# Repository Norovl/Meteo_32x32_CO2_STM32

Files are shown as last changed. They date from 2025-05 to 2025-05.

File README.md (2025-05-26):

Данный проект представляет собой метеостанцию с дополнительными возможностями, собранную на основе STM32F103C8T6.

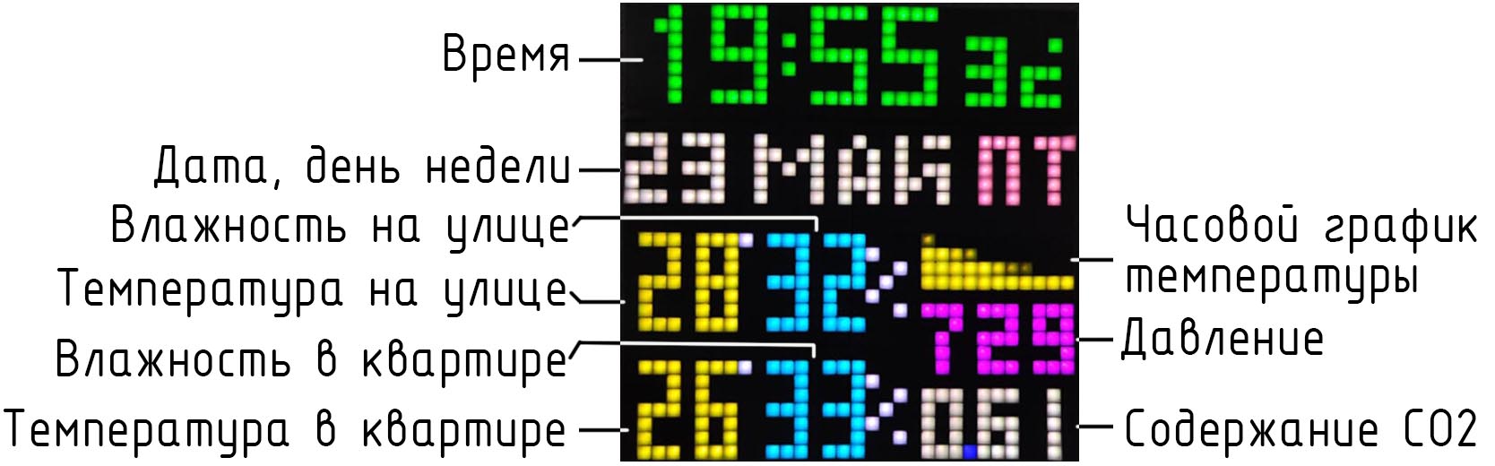
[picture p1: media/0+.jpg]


Станция может показывать:

**На главном экране:**

*   Время (часы);
*   Дату (число, месяц, день недели);
*   Температуру (ͦС) и влажность (%) на улице;
*   Температуру (ͦС) и влажность (%) в квартире;
*   Атмосферное давление воздуха (мм.рт.ст.)
*   Содержание СО2 в квартире (тыс.ppm);
*   Часовой график температуры (влажности, давления) на улице и/или температуру (влажность, СО2) в квартире.

**На дополнительных экранах:**

*   Текущую температуру (ͦС), влажность (относительную (%) и абсолютную (г/м3)), точку росы в квартире и на улице, давление, СО2 (ppm) с текущим минутным графиком по каждому из показателей;
*   Значение час назад и текущее значение температуры, влажности (относительной (%) и абсолютной (г/м3)), точки росы (ͦС) в квартире и на улице, давления, СО2 (ppm) с часовым графиком по каждому из показателей;
*   Суточный график с последовательным выводом значения за каждый час суток по следующим показателям: температура, влажность (относительная и абсолютная), точка росы в квартире и на улице, давление, СО2.

**Аппаратный состав проекта:**

([https://aliexpress.ru/item/1005003541972572.html?spm=a2g2w.orderdetail.0.0.49934aa6X7jbTa&sku\_id=12000026227682554&\_ga=2.192225709.602763749.1748060249-1858461858.1585985510](https://aliexpress.ru/item/1005003541972572.html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))

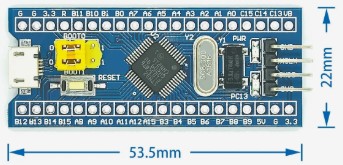
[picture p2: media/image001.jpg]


Состав датчиков:

1.  Два датчика BME280 (температура, влажность, давление). У одного из них нужно перепаять дорожку для изменения адреса подключения;

([https://aliexpress.ru/item/32862445164.html?spm=a2g2w.orderdetail.0.0.24634aa6IzSH7J&sku\_id=10000000058075622&\_ga=2.255525007.602763749.1748060249-1858461858.1585985510](https://aliexpress.ru/item/32862445164.html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))  
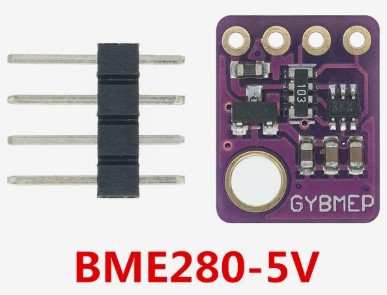
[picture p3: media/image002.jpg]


2.  Датчик MH-Z19B (СО2);

([https://aliexpress.ru/item/32371956420.html?sku\_id=12000035236616579&spm=a2g2w.productlist.search\_results.0.7c71c19cK1bYaC](https://aliexpress.ru/item/32371956420.html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))  
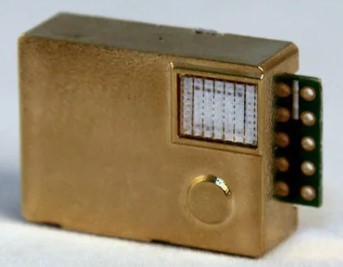
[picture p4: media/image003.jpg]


3.  Фоторезистор (необязателен) – нужен для автоматической регулировки яркости при изменении внешнего освещения).

([https://aliexpress.ru/item/1005007944797703.html?sku\_id=12000042961408154&spm=a2g2w.productlist.search\_results.1.56b92e913V1ALD](https://aliexpress.ru/item/1005007944797703.html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))

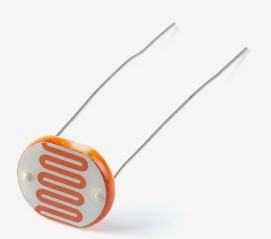
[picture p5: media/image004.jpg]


4.  В качестве панели отображения используются четыре WS2812B PIXELS PANEL размером 8 х 32 пикселей, соединенные сверху вниз, подключенные к контроллеру в нижнем углу (подключение и расположение панелей можно менять в настройках проекта).

([https://aliexpress.ru/item/4000544584524.html?spm=a2g2w.orderdetail.0.0.23ba4aa6R5I62Q&sku\_id=12000032067904150&\_ga=2.163242171.602763749.1748060249-1858461858.1585985510](https://aliexpress.ru/item/4000544584524.html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))

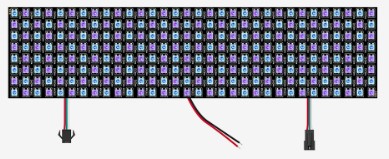
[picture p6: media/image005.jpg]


В качестве рассеивателя используется распечатанная на 3D принтере белая пластина в 2-3 слоя, наклеенная на черную распечатанную сетку.
В проекте приложены модели сетки и пластины размерами 8х8 и 16х8 пикселей. Для размера 32х32 нужно распечатать несколько сеток и пластин и склеить между собой. 
Обратите внимание - у сетки есть верх и низ. Сторона для наклеивания пластины плоская, на другой стороне часть сетки приподнято для сохранения места под резисторы обвязки панели.

Сетка:

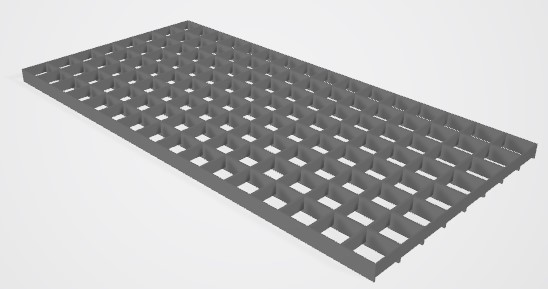
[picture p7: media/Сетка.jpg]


**Схема подключения:**

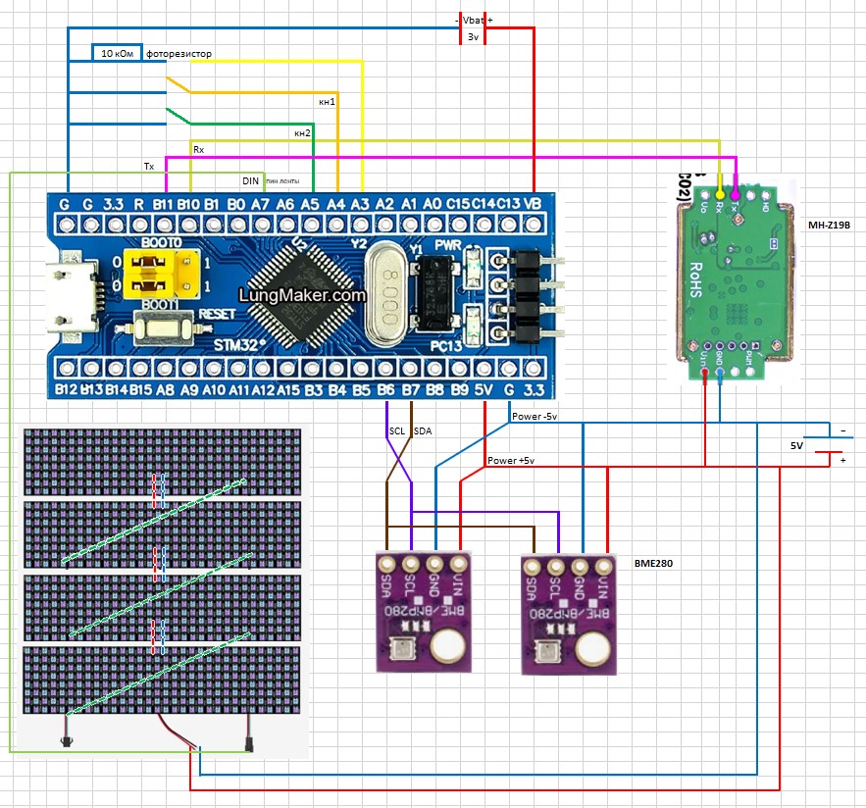
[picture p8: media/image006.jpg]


**Управление и настройка метеостанции:**

**Двойное нажатие** \[кн.1\] – в режим установки даты и времени. 
Дальнейшие нажатия \[кн.1\] - последовательное переключение настройки Год – Месяц – Число – Часы – Минуты – Секунды – Корректировка скорости хода часов\*.

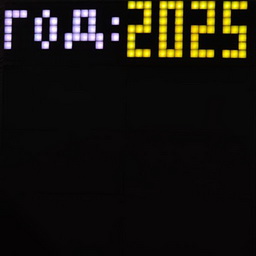
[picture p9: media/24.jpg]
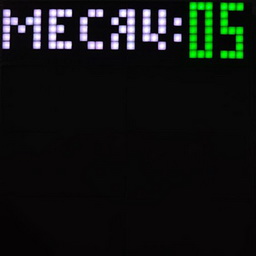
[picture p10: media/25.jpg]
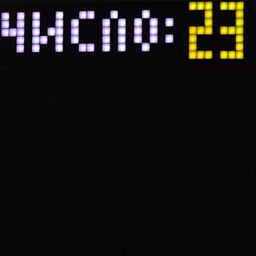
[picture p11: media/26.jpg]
  

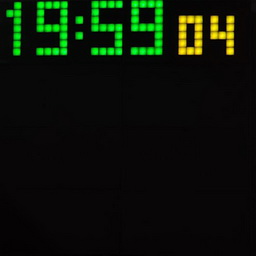
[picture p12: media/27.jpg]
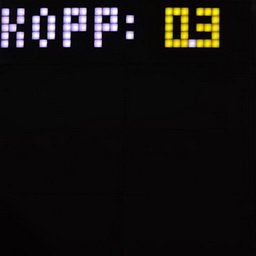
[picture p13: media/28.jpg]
 

Выйти из режима настройки - удержание \[кн.1\] или переключение последовательно всех настраиваемых элементов

Установка даты/времени производится путем:

**одинарного нажатия** \[кн.2\] - увеличение на единицу настраиваемое значение;

**удержания** \[кн.2\] - постоянное увеличение настраиваемого значения пока нажата кнопка;

**Двойного нажатия** \[кн.2\] – уменьшение на единицу настраиваемого значения;

**Двойного нажатия и удержания на втором нажатии \[кн.2\]** – постоянное уменьшение настраиваемого значения пока нажата кнопка

\*настройка скорости хода часов (сек/сут) (фактическая корректировка производится на целые секунды, т.е. если корректировка установлена как 0,2, то 1 раз в 5 суток добавляется 1 секунда);

**Пятикратное нажатие** \[кн.2\] – сохраняются настройки вида отображения показаний датчиков и часовых графиков.

**Одинарное нажатие** \[кн.2\] – последовательное переключение показаний в нижней части табло \[currentMode\]:

1.  (показания на улице (Out)) Температура + Влажность + График(и)/давление, (показания в квартире (In)) Температура + Влажность + График(и)/СО2. (отрицательные значения температуры отображаются синим цветом); \[0\]

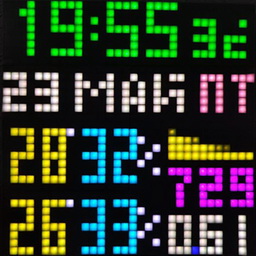
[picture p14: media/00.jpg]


2.  Температура на улице и в квартире до тысячных долей + часовой график; \[1\]

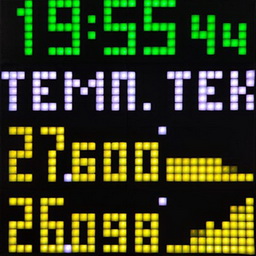
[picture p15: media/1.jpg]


3.  Относительная влажность (%) на улице и в квартире + часовой график; \[2\]

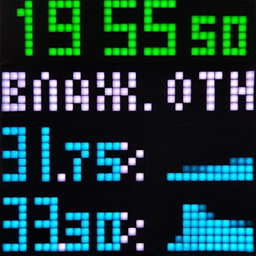
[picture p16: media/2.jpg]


4.  Абсолютная влажность (г/м3) на улице и в квартире + часовой график; \[3\]

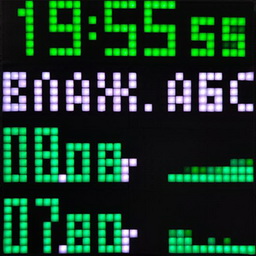
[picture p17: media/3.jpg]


5.  Давление до тысячных долей и содержание СО2 в квартире PPM; \[4\]  
    
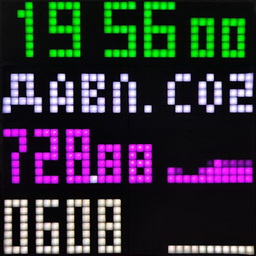
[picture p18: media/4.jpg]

	
6.  Точка росы на улице и в квартире + часовой график; \[5\]  
    
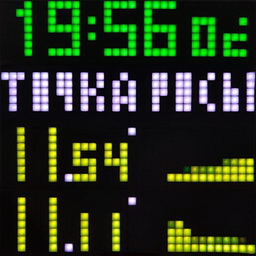
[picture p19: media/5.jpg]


7.  Температура за час (на начало и конец часа) на улице и в квартире; \[10\]  
	
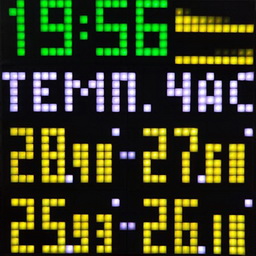
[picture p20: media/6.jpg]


8.  Относительная влажность (%) за час (на начало и конец часа) на улице и в квартире; \[11\]  
    
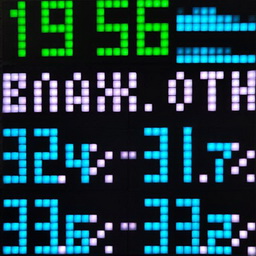
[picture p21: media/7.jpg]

	
9.  Абсолютная влажность (г/м3) за час (на начало и конец часа) на улице и в квартире; \[12\]
	
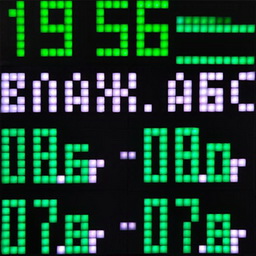
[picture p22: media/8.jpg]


10.  Давление и содержание СО2 за час (на начало и конец часа); \[13\]

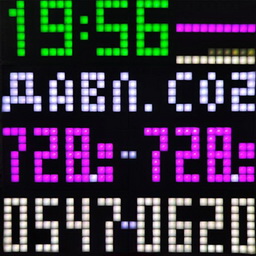
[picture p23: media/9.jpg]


11.  Точка росы за час (на начало и конец часа) на улице и в квартире; \[14\]

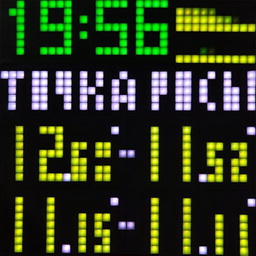
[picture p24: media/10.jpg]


12.  Суточный график температуры на улице и в квартире с последовательным отображением показаний за каждый час суток\*; \[20\]

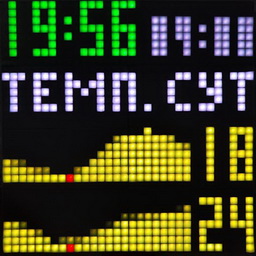
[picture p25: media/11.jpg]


13.  Суточный график относительной влажности (%) на улице и в квартире с последовательным отображением показаний за каждый час суток; \[21\]

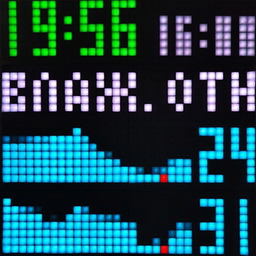
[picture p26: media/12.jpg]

	
14.  Суточный график абсолютной влажности (г/м3) на улице и в квартире с последовательным отображением показаний за каждый час суток; \[22\]

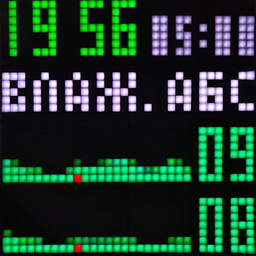
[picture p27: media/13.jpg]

	
15.  Суточный график давления и содержания СО2 с последовательным отображением показаний за каждый час суток; \[23\]

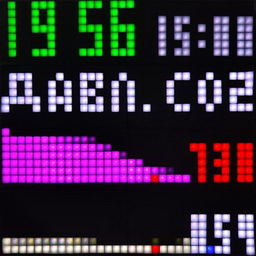
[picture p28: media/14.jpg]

	
16.  Суточный график точки росы на улице и в квартире с последовательным отображением показаний за каждый час суток; \[24\]

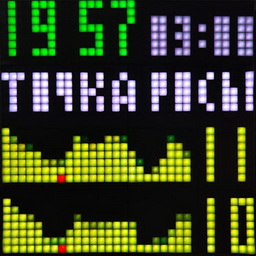
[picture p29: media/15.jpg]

	
\*в суточных графиках добавляется красная метка в нижней части, справа от графика отображается значение показателя (температура In, Out, влажность In, Out, давление, СО2, точка росы In, Out).

**Удержание** \[кн.1\] – автоматическое последовательное переключение показаний в нижней части табло как при одинарном нажатии.

**Одинарное нажатие** \[кн.1\] – переключение показаний в правой части 3 и 4 секции из 4-х:

1.  Часовой график температуры (влажности, давления)\* Out, давление, СО2


	
2.  Крупно давление, СО2

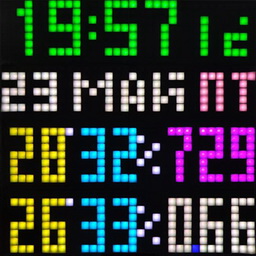
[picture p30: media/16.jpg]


3.  Часовой график температуры (влажности, давления) Out, давление, часовой график СО2 (температуры, влажности) In

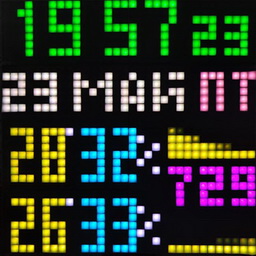
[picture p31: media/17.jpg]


4.  Крупно часовой график температуры (влажности, давления) Out, СО2

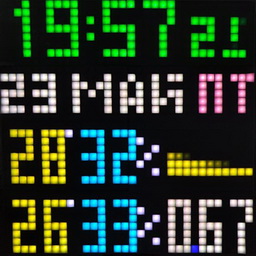
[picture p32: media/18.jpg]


5.  Часовой график температуры (влажности, давления) и влажности (давления, температуры) Out, СО2

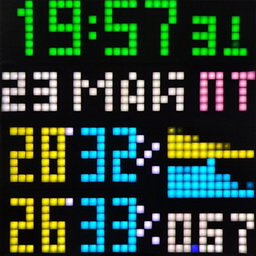
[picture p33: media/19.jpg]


6.  Крупно давление, часовой график СО2 (температуры, влажности) In

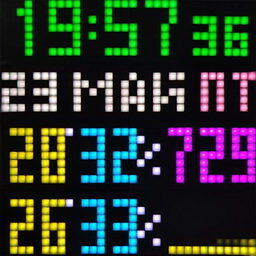
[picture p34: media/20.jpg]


7.  Давление, часовой график СО2 (температуры, влажности) и температуры (влажности, СО2) In

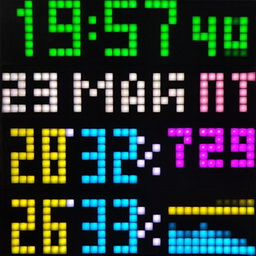
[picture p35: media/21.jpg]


8.  Часовой график температуры (влажности, давления) и влажности (давления, температуры) Out, часовой график СО2 (температуры, влажности) и температуры (влажности, СО2) In

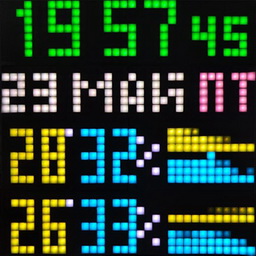
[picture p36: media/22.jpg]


9.  Крупно часовой график температуры (влажности, давления) Out, часовой график СО2 (температуры, влажности) In

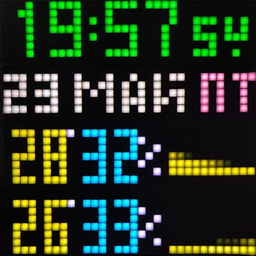
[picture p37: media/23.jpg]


\*какой график будет отображаться для графиков Out выбирается двойным нажатием \[кн.2\], для графиков In тройным нажатием \[кн.2\].

**Двойное нажатие** \[кн.2\] – последовательное переключение показаний часовых графиков Out температуры – влажности – давления

**Тройное нажатие** \[кн.2\] – последовательное переключение показаний часовых графиков In температуры – влажности – СО2

**Примечание**: плача чувствительна к качеству питания, поэтому для исключения зависания контроллера питайте плату стабилизированным напряжением 5В.

**Arduino IDE – выбор платы для загрузки:**

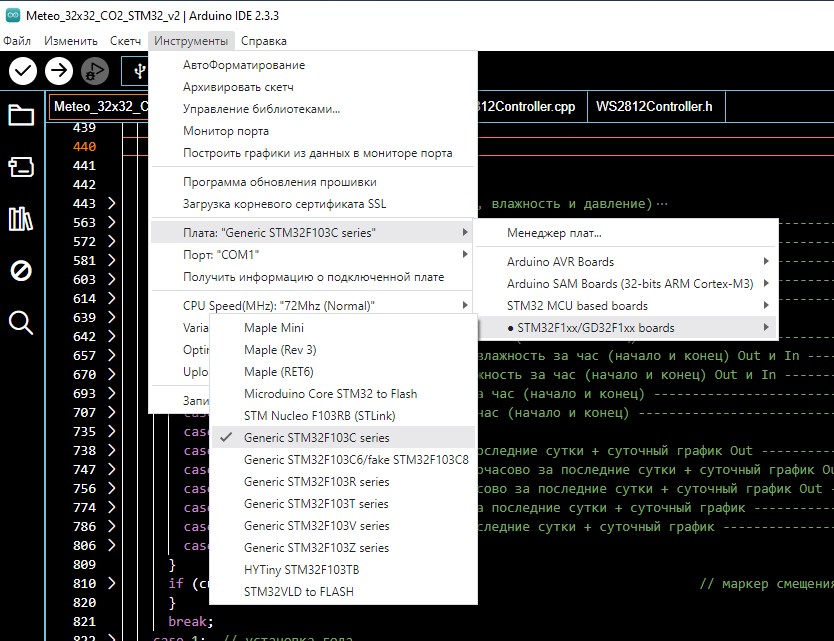
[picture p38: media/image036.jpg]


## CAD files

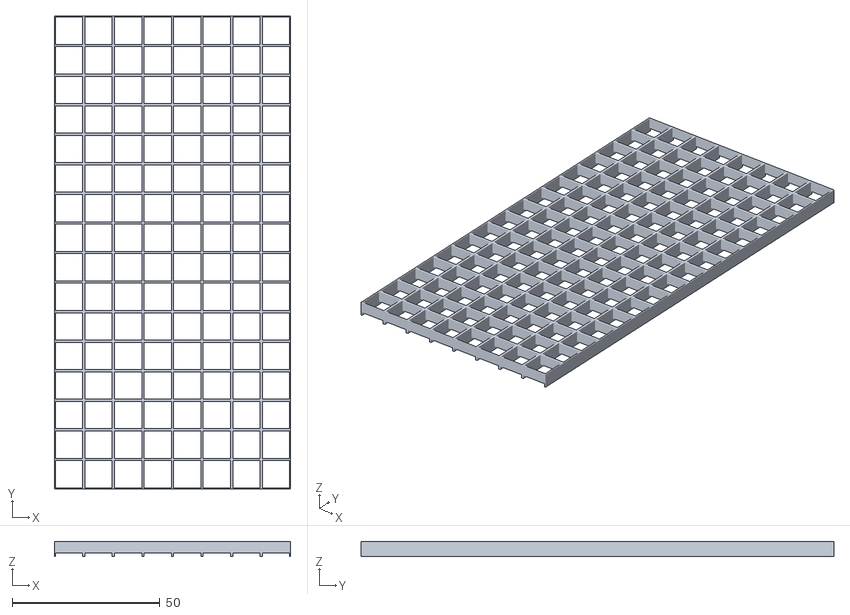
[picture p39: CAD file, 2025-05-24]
3D_Print/Сетка 16х8_(Black).stl
80.0 x 160.0 x 5.00

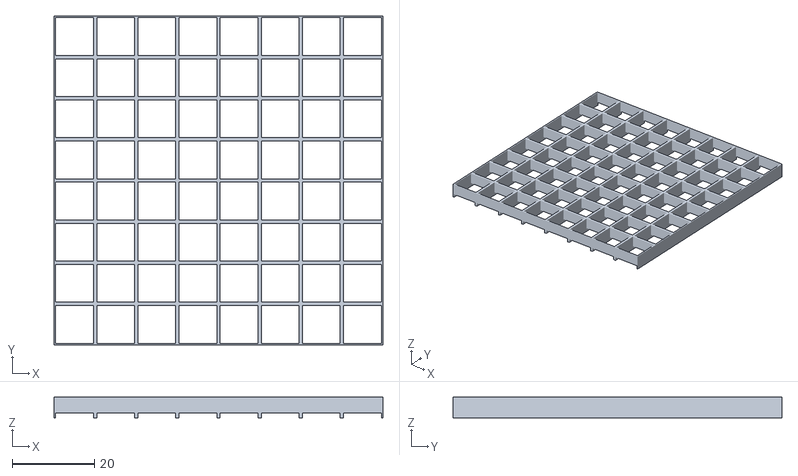
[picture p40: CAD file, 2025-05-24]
3D_Print/Сетка 8х8_(Black).stl
80.0 x 80.0 x 5.00

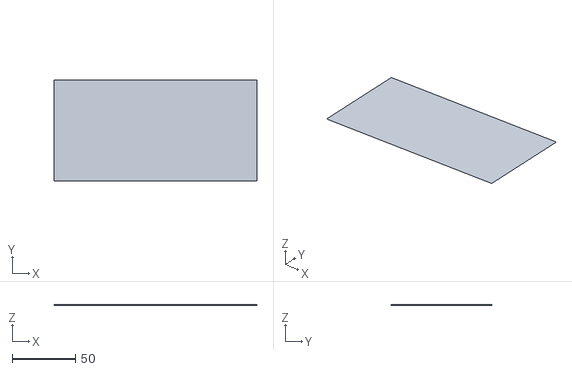
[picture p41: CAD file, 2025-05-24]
3D_Print/TopOnMeteo_16x8_(White).stl
160.0 x 80.0 x 0.4

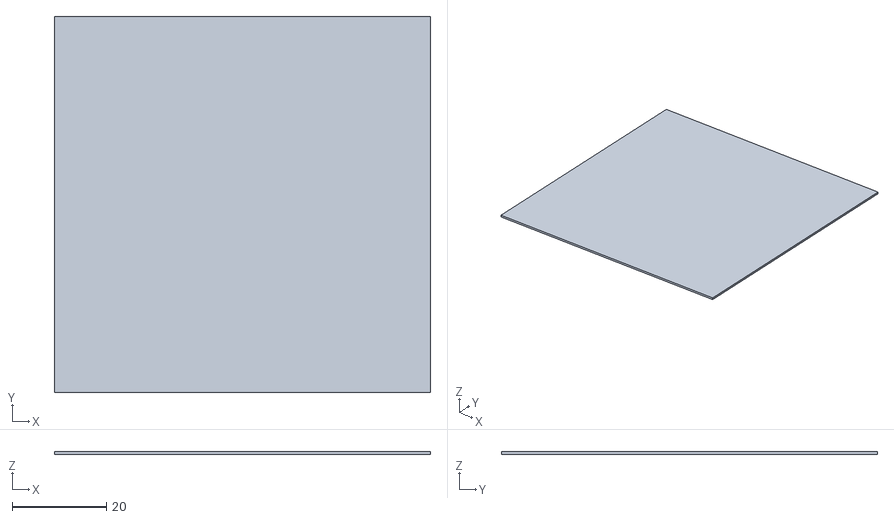
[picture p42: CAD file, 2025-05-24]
3D_Print/TopOnMeteo_8x8_(White).stl
80.0 x 80.0 x 0.6

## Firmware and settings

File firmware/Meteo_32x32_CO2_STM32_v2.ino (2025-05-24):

// ============= НАСТРОЙКИ =============

#define LEDDriver 0  // 0 - встроенная самописная библиотека управления лентой (первый пиксель не мигает), 1 - универсльная (первый пиксель мигает)
#define BMEOUTON 2   // 0 - отключает (отладка), 1 - включает BME280I2C bmeOut, 2 - включает BlueDot_BME280 bmeOut, 3 - включает GyverBME280 bmeOut
#define BMEINON 2    // 0 - отключает (отладка), 1 - включает BME280I2C bmeIn, 2 - включает BlueDot_BME280 bmeIn, 3 - включает GyverBME280 bmeIn

//#define F_CPU 72000000

// ---------- МАТРИЦА ---------
#define DATA_PIN PA7        // пин ленты
#define BRIGHTNESS 20       // стандартная максимальная яркость (0-255)
#define minBRIGHTNESS 2     // минимальная яркость (1-BRIGHTNESS)
#define CURRENT_LIMIT 1000  // лимит по току в миллиамперах, автоматически управляет яркостью (пожалей свой блок питания!) 0 - выключить лимит

// ============= ДЛЯ РАЗРАБОТЧИКОВ =============
#define BTNMain_PIN PA4  // пин основной кнопки
#define BTNTime_PIN PA5  // пин кнопки установки времени
#define PHOTO PA3        // фотодатчик для настройки яркости

#define M_WIDTH 128                    // ширина матрицы
#define M_HEIGHT 8                     // высота матрицы
#define NUM_LEDS (M_WIDTH * M_HEIGHT)  // для удобства запомним и количество ледов

// ---------------- БИБЛИОТЕКИ -----------------
#if (LEDDriver == 0)
#include "WS2812Controller.h"  // светодиодная панель (самописная, сокращенная)
#elif (LEDDriver == 1)
#include <FastLED.h>  // светодиодная панель (универсльная библиотека)
#endif
#include <stm32f1_rtc.h>     // Дата, время
#include <BME280I2C.h>       // 1 вид подключения
#include <BlueDot_BME280.h>  // 2 вид подключения
#include <GyverBME280.h>     // 3 вид подключения
#include <Wire.h>
#include <GyverButton.h>
#include <EEPROM.h>
#include <MHZ19.h>  // датчик СО2


#define BME280_ADDRESS_OUT 0x77
#define BME280_ADDRESS_IN 0x76
#if (BMEOUTON == 1)
BME280I2C bmeOut;
#elif (BMEOUTON == 2)
BlueDot_BME280 bmeOut;
#elif (BMEOUTON == 3)
GyverBME280 bmeOut;
#endif
#if (BMEINON == 1)
BME280I2C bmeIn;  // Создание обьекта bme
#elif (BMEINON == 2)
BlueDot_BME280 bmeIn;
#elif (BMEINON == 3)
GyverBME280 bmeIn;
#endif


// инициализация у матрицы такая же, как у ленты, но добавляются параметры в (скобках)
#if (LEDDriver == 0)
static WS2812Controller ledStrip(NUM_LEDS, DATA_PIN);
#elif (LEDDriver == 1)
CRGB leds[NUM_LEDS];
#endif

// вид подключения
enum m_Type { ZIGZAG,
              PARALLEL };

enum m_Connection { LEFT_BOTTOM,
                    LEFT_TOP,
                    RIGHT_TOP,
                    RIGHT_BOTTOM };

enum m_Dir { DIR_RIGHT,
             DIR_UP,
             DIR_LEFT,
             DIR_DOWN };

// угол подключения: 0 LEFT_BOTTOM - левый нижний, 1 LEFT_TOP - левый верхний, 2 RIGHT_TOP - правый верхний, 3 RIGHT_BOTTOM - правый нижний
// направление ленты из угла подключения: 0 DIR_RIGHT - вправо, 1 DIR_UP - вверх, 2 DIR_LEFT - влево, 3 DIR_DOWN - вниз
//microLED<NUM_LEDS, M_PIN, MLED_NO_CLOCK, LED_WS2812, ORDER_GRB, CLI_AVER> matrix(M_WIDTH, M_HEIGHT, ZIGZAG, RIGHT_TOP, DIR_DOWN);
//matrixConfig( (uint8_t)УголПодключения | ((uint8_t)направление << 2))
// тип матрицы: 0 ZIGZAG - зигзаг, 1 PARALLEL - параллельная
int8_t matrixType = ZIGZAG;
int8_t matrixConfig = ((RIGHT_BOTTOM) | (DIR_UP << 2));
int8_t matrixW;

static const char *weekdayName[] = { "ВС", "ПН", "ВТ", "СР", "ЧТ", "ПТ", "СБ" };
static const char *monthName[] = { "ЯНВ", "ФЕВ", "МАР", "АПР", "МАЙ", "ИЮН", "ИЮЛ", "АВГ", "СЕН", "ОКТ", "НОЯ", "ДЕК" };

// переменные для времени
uint32_t epochTime, epochTimePrev, startepochTime;
byte hoursPrev = 0, minutesPrev = 0, secondsPrev = 0;
int16_t years = 0, months = 0, days = 0;
byte hours = 0, minutes = 0, seconds = 0;
DateVar date;
TimeVar time;
STM32F1_RTC rtc;
int8_t corhr = 0;  // корректировка точности хода часов за 10 дней, секунды (+/-)

MHZ19 myMHZ19;

// ------------------- ТИПЫ --------------------
//GButton button(BTN_PIN, LOW_PULL, NORM_OPEN); // для физической кнопки
GButton buttonMain(BTNMain_PIN, HIGH_PULL, NORM_OPEN);  // для основной кнопки
GButton buttonTime(BTNTime_PIN, HIGH_PULL, NORM_OPEN);  // для кнопки времени

// ----------------- ПЕРЕМЕННЫЕ ------------------

// цвета
const int32_t mWhite = 0xFFFFFF,  // белый
  mSilver = 0xC0C0C0,             // серебро
  mGray = 0x808080,               // серый
  mBlack = 0x000000,              // чёрный
  mRed = 0xFF0000,                // красный
  mMaroon = 0x800000,             // бордовый
  mOrange = 0xFF3000,             // оранжевый
  mYellow = 0xFFFF00,             // жёлтый 0xFF8000,
  mOlive = 0x808000,              // олива
  mLime = 0x00FF00,               // лайм
  mGreen = 0x008000,              // зелёный
  mAqua = 0x00FFFF,               // аква
  mTeal = 0x008080,               // цвет головы утки чирка
  mBlue = 0x0000FF,               // синий
  mNavy = 0x000080,               // тёмно-синий
  mMagenta = 0xFF00FF,            // розовый
  mPurple = 0x800080;             // пурпурный

// ----------------- переменные для вывода -----------------
float dispTempOut, dispTempIn;
float dispHumOut, dispHumIn;
float dispPresOut, dispPresIn;
float dispCO2 = 400;
float tmp;  // временная переменная - для содержания влаги в воздухе г/м3 при просмотре влажности с долями

int32_t colorTempIn, colorTempOut;  // цвета температуры для дома и улицы

// ----------------- массивы графиков -----------------
float tempDayIn[24], tempDayOut[24], tempHourIn[11], tempHourOut[11], tempMinIn[11], tempMinOut[11];
float humDayIn[24], humDayOut[24], humHourIn[11], humHourOut[11], humMinIn[11], humMinOut[11];
float pressDayOut[24], pressHourOut[11], pressMinOut[11];
float CO2Day[24], CO2Hour[11], CO2Min[11];
float tmp24In[24], tmp24Out[24];
int8_t hourInDay;          // указатель на час сутки назад (-24 + hourInDay) в суточных графиках для отображения параметра температуры, влажности, давления на указанный час (включается двойное нажатие с удержанием первой кнопки)
uint8_t updatedGraph = 7;  // признак обновления основных графиков для обновления временных (tmp) графиков. Бит 1 = 1 - обновился суточный график, Бит 2 = 1 - обновился часовой график, Бит 3 = 1 - обновился минутный график, Бит 8 = 1 - было нажатие кнопки Main
uint8_t newSec = 255;      // при обновлении секунды присваивается 255 для битового сравнения

// Массив указателей на переменные
//float *arrHourOut[4] = { tempHourOut, humHourOut, pressHourOut, tmp24Out };
//float *arrHourIn[4] = { tempHourIn, humHourIn, CO2Hour, tmp24In };
//const int32_t *arrColor[4] = { &colorTempOut, &mAqua, &mMagenta, &mBlue };

// ----------------- вид экрана -----------------
byte timeSet = 0;                        // 0 - рабочий режим, 1 - установка года, 2 - месяца, 3 - дня, 4 - часов, 5 - минут, 6 - секунд.
byte currentMode = 0;                    // основной режим отображения (0 - температура, влажность, давление; текщее: 1 - температура; 2 - влажность, 3 - абс.влажность; 4 - давление/CO2; 5 - точка росы; за последний час: 10-14... за сутки 20-24...)
byte graphModeIn = 0, graphModeOut = 0;  // отображение графика In/Out  (0 - температура, 1 - влажность, 2 - давление)
byte graphMode = 8;                      // вид табло в правой части в основном режиме (0 - давлениеOut-CO2, 1 - графикOut-давлениеOut-графикIn, 2 - графикOut-CO2, 3 - графикOut1-графикOut2-CO2, 4 - давлениеOut-графикIn, 5 - давлениеOut-графикIn1-графикIn2, 6 - графикOut1-графикOut2-графикIn1-графикIn2, 7 - графикOut-графикIn, 8  - графикOut-давлениеOut-CO2)
byte x, y, w, h, z;                      // для графиков координаты x, y, ширина, высота и кол-во значений на пиксель (глубина/масштаб)
int8_t numBME = 0;                       // для чередования чтения датчиков BME
byte scroll = 0;                         // строки скролла при изменении цифр
byte bright = 1;                         // яркость
int16_t getbright = 4000;                // яркость, полученная от датчика
boolean hulfTime;                        // полусекундие :)

//----------------- таймеры -----------------
unsigned long sensorsTimer = 150, sensorsTimerD = 0;  // время обновления показаний сенсоров в памяти, миллисекунд !!!250 * (231 / 360) - отставание скорости тиков millis()
unsigned long redrawTimer = 40, redrawTimerD = 0;     // время обновления показаний экрана, миллисекунд
unsigned long holdTimer = 700, holdTimerD = 0;        // время удержания кнопки для смены формата графиков, миллисекунд
unsigned long holdSetTime = 150, holdSetTimeD = 0;    // время удержания кнопки при установке даты/времени, миллисекунд
unsigned long CO2Timer = 5000, CO2TimerD = 0;         // время обновления показаний CO2 в памяти, миллисекунд


// ====================== Настройка ===============================================================================================================================================
void setup() {

  buttonMain.setStepTimeout(100);
  buttonMain.setClickTimeout(500);
  buttonTime.setStepTimeout(100);
  buttonTime.setClickTimeout(500);

  Serial.begin(9600);
  Serial3.begin(9600);
  myMHZ19.begin(Serial3);
  myMHZ19.autoCalibration(false);
  dispCO2 = myMHZ19.getCO2();  // первое считывание пустое

#if (LEDDriver == 1)
  FastLED.addLeds<NEOPIXEL, DATA_PIN>(leds, NUM_LEDS);  //NEOPIXEL  WS2812B
#endif

  // https://github.com/ZulNs/STM32F1_RTC

  if (!rtc.begin()) Serial.println("RTS not started!");
  else Serial.println("RTS started");

  epochTime = rtc.getTime();
  if (epochTime < 1000) {     // если дата и время не сохранено, ставим дефолтное
    rtc.setTime(1723852741);  // excel =(СЕГОДНЯ()-ДАТА(1970;1;1))*86400+ВРЕМЯ(7;15;1)*86400 или =(ДАТА(2024;4;30)-ДАТА(1970;1;1))*86400+ВРЕМЯ(23;59;1)*86400

    //описание функций __TIME__ и __DATE__
    //https://stackoverflow.com/questions/11697820/how-to-use-date-and-time-predefined-macros-in-as-two-integers-then-stri
    epochTime = rtc.getTime();
  }
  startepochTime = epochTime;
  rtc.epochToDate(epochTime, date);
  rtc.epochToTime(epochTime, time);

  // Радужная шахматка:////////////////////////////////////////////////////////////////////////////////////////////////////////////////
  for (uint16_t x = 0; x < 64; x++) {
    for (uint16_t i = 0; i < 256; i++) {  //NUM_LEDS
#if (LEDDriver == 0)
      ledStrip.setPixel(i * 2, brightRatio(Wheel((i * 2 + x * 8) & 255), 19 - abs(map(x, 0, 63, -19, 19)), 0));
      ledStrip.setPixel((i * 2 + 256), brightRatio(Wheel((i * 2 + x * 8) & 255), 19 - abs(map(x, 0, 63, -19, 19)), 0));
      ledStrip.setPixel((i * 2 + 512), brightRatio(Wheel((i * 2 + x * 8) & 255), 19 - abs(map(x, 0, 63, -19, 19)), 0));
      ledStrip.setPixel((i * 2 + 768), brightRatio(Wheel((i * 2 + x * 8) & 255), 19 - abs(map(x, 0, 63, -19, 19)), 0));
      ledStrip.setPixel(255 - (i * 2), brightRatio(Wheel((i * 2 + x * 8) & 255), 19 - abs(map(x, 0, 63, -19, 19)), 0));
      ledStrip.setPixel(511 - (i * 2), brightRatio(Wheel((i * 2 + x * 8) & 255), 19 - abs(map(x, 0, 63, -19, 19)), 0));
      ledStrip.setPixel(767 - (i * 2), brightRatio(Wheel((i * 2 + x * 8) & 255), 19 - abs(map(x, 0, 63, -19, 19)), 0));
      ledStrip.setPixel(1023 - (i * 2), brightRatio(Wheel((i * 2 + x * 8) & 255), 19 - abs(map(x, 0, 63, -19, 19)), 0));
#elif (LEDDriver == 1)
      leds[i * 2] = brightRatio(Wheel((i * 2 + x * 8) & 255), 19 - abs(map(x, 0, 63, -19, 19)), 0);
      leds[i * 2 + 256] = brightRatio(Wheel((i * 2 + x * 8) & 255), 19 - abs(map(x, 0, 63, -19, 19)), 0);
      leds[i * 2 + 512] = brightRatio(Wheel((i * 2 + x * 8) & 255), 19 - abs(map(x, 0, 63, -19, 19)), 0);
      leds[511 - (i * 2)] = brightRatio(Wheel((i * 2 + x * 8) & 255), 19 - abs(map(x, 0, 63, -19, 19)), 0);
      leds[767 - (i * 2)] = brightRatio(Wheel((i * 2 + x * 8) & 255), 19 - abs(map(x, 0, 63, -19, 19)), 0);
      leds[1023 - (i * 2)] = brightRatio(Wheel((i * 2 + x * 8) & 255), 19 - abs(map(x, 0, 63, -19, 19)), 0);
#endif
    }
#if (LEDDriver == 0)
    ledStrip.show();
#elif (LEDDriver == 1)
    FastLED.show();
#endif
  }
  // ///////////////////////////////////////////////////////////////////////////////////////////////////////////////////////////////////

  EEPROM.init();

  if (((int8_t)(EEPROM.read(0)) >= 100) || ((int8_t)(EEPROM.read(0)) <= -100)) EEPROM.write(0, corhr);  // если мусор, то по умолчанию
  corhr = (int8_t)EEPROM.read(0);
  //if ((((EEPROM.read(4))) > 18) || (((EEPROM.read(4))) < 0)) EEPROM.write(4, viewTime);  // если мусор, то по умолчанию
  //viewTime = (EEPROM.read(4));
  if ((((EEPROM.read(8))) > 3) || (((EEPROM.read(8))) < 0)) EEPROM.write(8, currentMode);  // если мусор, то по умолчанию
  currentMode = (EEPROM.read(8));
  if ((((EEPROM.read(12))) > 2) || (((EEPROM.read(12))) < 0)) EEPROM.write(12, graphModeIn);  // если мусор, то по умолчанию
  graphModeIn = (EEPROM.read(12));
  if ((((EEPROM.read(16))) > 2) || (((EEPROM.read(16))) < 0)) EEPROM.write(16, graphModeOut);  // если мусор, то по умолчанию
  graphModeOut = (EEPROM.read(16));
  if ((((EEPROM.read(20))) > 8) || (((EEPROM.read(20))) < 0)) EEPROM.write(20, graphMode);  // если мусор, то по умолчанию
  graphMode = (EEPROM.read(20));


  //RTC_SECONDS_INTERRUPT An occured event every time the RTC counter register incremented.
  //secondsTick - The function to call when the interrupt occurs.
  //rtc.attachInterrupt(RTC_SECONDS_INTERRUPT, secondsTick);
  //можно вместо прерывания выше использовать контрукцию в LOOP:
  //if (rtc.isCounterUpdated()) {rtc.clearSecondFlag();}

  pinMode(PHOTO, INPUT_PULLUP);
  pinMode(PB6, INPUT_PULLUP);  // подтяжка пина BME (работает и без этого)
  pinMode(PB7, INPUT_PULLUP);  // подтяжка пина BME (работает и без этого)
                               //pinMode(PA7, INPUT_PULLUP);  // подтяжка пина LED (работает и без этого)

  Wire.begin();
  Wire.setClock(20000);  // снижаем частоту шины до 20 кГц (со стандартных 100кГц) для упрощения прохождения сигнала по длинному проводу BME280 (при 10кГц анимация экрана подтормаживает (смена секунд))
  //Serial.println("Wire started");

// Настройка адреса и инициализация первого сенсора
#if (BMEOUTON == 1)
  BME280I2C::Settings settingsOut;
  settingsOut.bme280Addr = BME280I2C::I2CAddr_0x77;  // поменять на 77!!!
  bmeOut.setSettings(settingsOut);
  if (!bmeOut.begin()) Serial.println("Out Could not find BME280 sensor!");
  else Serial.println("Out BME280 sensor started");
#elif (BMEOUTON == 2)
  bmeOut.parameter.communication = 0;           //I2C communication for Sensor 1
  bmeOut.parameter.I2CAddress = 0x77;           //Set the I2C address of your breakout board
  bmeOut.parameter.sensorMode = 0b11;           //Setup Sensor mode for Sensor 1
  bmeOut.parameter.IIRfilter = 0b100;           //IIR Filter for Sensor 1
  bmeOut.parameter.humidOversampling = 0b101;   //Humidity Oversampling for Sensor 1
  bmeOut.parameter.tempOversampling = 0b101;    //Temperature Oversampling for Sensor 1
  bmeOut.parameter.pressOversampling = 0b101;   //Pressure Oversampling for Sensor 1
  bmeOut.parameter.pressureSeaLevel = 1013.25;  //default value of 1013.25 hPa (Sensor 1)
  bmeOut.parameter.tempOutsideCelsius = 15;     //default value of 15°C
  bmeOut.parameter.tempOutsideFahrenheit = 59;  //default value of 59°F
  bmeOut.init();
#elif (BMEOUTON == 3)
  //bmeOut.setStandbyTime(STANDBY_10MS);
  bmeOut.setMode(NORMAL_MODE);
  bmeOut.begin(BME280_ADDRESS_OUT);
#endif

// Настройка адреса и инициализация второго сенсора
#if (BMEINON == 1)
  BME280I2C::Settings settingsIn;
  settingsIn.bme280Addr = BME280I2C::I2CAddr_0x76;
  bmeIn.setSettings(settingsIn);
  if (!bmeIn.begin()) Serial.println("In Could not find BME280 sensor!");
  else Serial.println("In BME280 sensor started");
#elif (BMEINON == 2)
  bmeIn.parameter.communication = 0;           //I2C communication for Sensor 2
  bmeIn.parameter.I2CAddress = 0x76;           //Set the I2C address of your breakout board
  bmeIn.parameter.sensorMode = 0b11;           //Setup Sensor mode for Sensor 2
  bmeIn.parameter.IIRfilter = 0b100;           //IIR Filter for Sensor 2
  bmeIn.parameter.humidOversampling = 0b101;   //Humidity Oversampling for Sensor 2
  bmeIn.parameter.tempOversampling = 0b101;    //Temperature Oversampling for Sensor 2
  bmeIn.parameter.pressOversampling = 0b101;   //Pressure Oversampling for Sensor 2
  bmeIn.parameter.pressureSeaLevel = 1013.25;  //default value of 1013.25 hPa (Sensor 2)
  bmeIn.parameter.tempOutsideCelsius = 15;     //default value of 15°C
  bmeIn.parameter.tempOutsideFahrenheit = 59;  //default value of 59°F
  bmeIn.init();                                //if (bme2.init() != 0x60) bme2Detected = 0;
#elif (BMEINON == 3)
  //bmeIn.setStandbyTime(STANDBY_10MS);
  bmeIn.setMode(NORMAL_MODE);
  bmeIn.begin(BME280_ADDRESS_IN);
#endif

  readSensors(0);
  delay(250);
  readSensors(0);

  if (matrixConfig == 4 || matrixConfig == 13 || matrixConfig == 14 || matrixConfig == 7) matrixW = M_HEIGHT;
  else matrixW = M_WIDTH;

  for (byte i = 0; i < 24; i++) {  // счётчик от 0 до 10
    if (i < 11) {
      tempHourIn[i] = dispTempIn;
      tempHourOut[i] = dispTempOut;
      humHourIn[i] = dispHumIn;
      humHourOut[i] = dispHumOut;
      pressHourOut[i] = dispPresOut;
      CO2Hour[i] = 400;
      tempMinIn[i] = dispTempIn;
      tempMinOut[i] = dispTempOut;
      humMinIn[i] = dispHumIn;
      humMinOut[i] = dispHumOut;
      pressMinOut[i] = dispPresOut;
      CO2Min[i] = 400;
    }
    tempDayIn[i] = dispTempIn;
    tempDayOut[i] = dispTempOut;
    humDayIn[i] = dispHumIn;
    humDayOut[i] = dispHumOut;
    pressDayOut[i] = dispPresOut;
    CO2Day[i] = 400;  //dispCO2;
  }
}
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
void loop() {

  // обновление экрана
  if ((testTimer(redrawTimerD, redrawTimer))) {
    if (scroll > 0) scroll++;
    if (scroll > 12) scroll = 0;
    hulfTime = (rtc.getMilliseconds() < 500);
    if (epochTime != rtc.getTime()) {
      //  if (rtc.isCounterUpdated()) {       // !!!закомментил, т.к. с этой строкой первый пиксель может мигать. Но работает и так
      //  rtc.clearSecondFlag();            // !!!закомментил, т.к. с этой строкой первый пиксель может мигать. Но работает и так
      epochTime = rtc.getTime();
      rtc.epochToDateTime(epochTime, date, time);
      if ((corhr != 0) && (corhr != 127)) {
        if (epochTime % ((int32_t)(86400 / ((float)abs(corhr) / 10))) == 0) {
          rtc.setTime(epochTime + ((corhr > 0) ? 1 : (-1)));  // корректировка хода часов
          corhr = 127;                                        // чтобы не было повторной корректировки на следующей секунде
        }
      } else {
        if (corhr == 127) corhr = (int8_t)EEPROM.read(0);  // возвращаем значение коэффициента после корректировки времени
      }
    }
    if (epochTime != epochTimePrev) {
      epochTimePrev = epochTime;
      hoursPrev = hours;
      minutesPrev = minutes;
      secondsPrev = seconds;
      hours = time.hours;
      minutes = time.minutes;
      seconds = time.seconds;
      newSec = 255;
      if (seconds == 0 && minutes == 0) plotSensorsDayTick();             // если новый час, то обновляем суточные графики
      if (((minutes % 6) == 0) && (seconds == 0)) plotSensorsHourTick();  // обновление графиков 1 раз в 6 минут (10 показаний в час)
      if ((seconds % 6) == 0) plotSensorsMinTick();                       // обновление графиков 1 раз в 6 секунд (10 показаний в минуту)
      scroll = 1;
    }
    drawScreen();  // перерисовываем экран
    // обновление датчиков
    if ((testTimer(sensorsTimerD, sensorsTimer))) readSensors(2);      // читаем показания датчиков температуры, влажности, давления
    if ((testTimer(CO2TimerD, CO2Timer))) dispCO2 = myMHZ19.getCO2();  // читаем показание датчика CO2
  }

  modesTick();  // тики кнопки
}

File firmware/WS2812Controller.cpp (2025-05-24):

#include "WS2812Controller.h"

WS2812Controller::WS2812Controller(uint16_t numLeds, uint8_t pin)
  : num_leds(numLeds), dataPin(pin), mPinMask(1 << pin) {
  leds_ = new uint8_t[num_leds * 3];

  // Настройка GPIO (выбранный пин как выход)
  RCC_APB2ENR |= (1 << 2);  // Включение тактирования GPIOA
  GPIOA->CRL = (GPIOA->CRL & ~(0xF << (dataPin * 4))) | (0x3 << (dataPin * 4));
  clear();
}

WS2812Controller::~WS2812Controller() {
  delete[] leds_;
}

void WS2812Controller::EnableCycleCounter() {
  DEMCR |= (1 << 24);  // DEMCR_TRCENA
  DWT_CYCCNT = 0;
  DWT[0] |= 1;  // DWT_CTRL_CYCCNTENA
}

void WS2812Controller::write8Bits(uint8_t b) {
  for (uint32_t i = 8; i > 0; i--) {
    while (DWT_CYCCNT < next_mark)
      ;
    GPIOA->ODR |= mPinMask;  // HIGH

    next_mark += (b & 0x80) ? T1H : T0H;
    while (DWT_CYCCNT < next_mark)
      ;

    GPIOA->ODR &= ~mPinMask;  // LOW
    next_mark += (b & 0x80) ? T1L : T0L;
    b <<= 1;
  }
}

void WS2812Controller::setColor(uint16_t led, uint8_t red, uint8_t green, uint8_t blue) {
  if (led >= num_leds) return;
  uint16_t i = led * 3;
  leds_[i++] = green;
  leds_[i++] = red;
  leds_[i] = blue;
}

void WS2812Controller::setPixel(int16_t Num, uint32_t Col) {
  setColor(Num, (Col >> 16) & 0xFF, (Col >> 8) & 0xFF, Col & 0xFF);
}

void WS2812Controller::clear() {
  for (uint16_t i = 0; i < num_leds * 3; i++) {
    leds_[i] = 0;
  }
}

void WS2812Controller::show() {

  // Отключаем все глобальные прерывания
  asm volatile("cpsid i");

  EnableCycleCounter();
  next_mark = T1H;
  for (uint16_t i = 0; i < num_leds * 3; i++) {
    write8Bits(leds_[i]);
  }

  GPIOA->ODR &= ~mPinMask;  // LOW
  while (DWT_CYCCNT < next_mark + 600000 / 14)
    ;

  // Включаем прерывания обратно
  asm volatile("cpsie i");
}

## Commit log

2025-05-24 Meteo 32x32
    [Схема.xlsx]
2025-05-24 Upd 3D
    [TopOnMeteo_16x8_(White).stl, TopOnMeteo_8x8_(White).stl, Сетка 16х8_(Black).stl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]
